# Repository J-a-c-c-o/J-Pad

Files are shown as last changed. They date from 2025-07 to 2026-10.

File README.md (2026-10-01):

# J-Pad

A custom 4x4 handwired macropad with rotary encoder, a configuration GUI and a
layout that survives a reboot.

<div style="display: flex; justify-content: center; gap: 20px;">
  Macropad Top View
  Macropad Side View
</div>

## Overview

This project is a handwired 4x4 macropad built around a Raspberry Pi Pico and QMK firmware. The firmware maps each physical key to a macro slot, and the host application in `host/` reads and writes those macros at runtime over raw HID.

The encoder has layer-aware behavior, and the firmware supports 16 logical layers with 16 macros per layer.

Layouts live in RAM while you edit them and are written to the flash of the Pico by an explicit save, so the board keeps its layout over a reboot. The host application talks to the board with a small request/response protocol over raw HID and ships a GUI that edits the layout the board is currently running.

## Requirements

### Hardware

- 1x Raspberry Pi Pico
- 16x Cherry MX compatible switches (or 15 switches plus encoder push if available)
- 1x Rotary encoder (EC11)
- 16x 1N4148 diodes
- 4x 3M 10mm DIN 965 screws (or similar)
- Hookup wire for handwiring
- Keycaps for 16 keys
- MX encoder adapter: [Thingiverse Thing:3770166](https://www.thingiverse.com/thing:3770166)

### Software

- [QMK Firmware](https://qmk.fm/) for firmware compilation/customization
- [Rust](https://www.rust-lang.org/tools/install) (stable) for the host application
- Computer with USB port

### Tools (for assembly)

- Soldering iron and solder
- Wire strippers
- 3D printer or printing service
- Basic hand tools

## Quick Start

### Flash Firmware

1. Hold the top-left key while plugging in USB.
2. Copy `jpad_4x4_macropad_default.uf2` to the `RPI-RP2` drive.
3. The board will reboot with the loaded firmware.

### Default Behavior

The firmware maps the 16 keys to macro indices `0..15` on every layer. The actual key behavior is defined by macros, so the board is configured from the host application in `host/`.

The first boot has no stored layout, so the firmware falls back to a built-in default layout: media keys, a mute key, function keys, a repeating left mouse button, and four keys that switch to the other layers. The encoder changes the volume on every layer, except for a few layers where it scrolls, zooms, scrolls again or skips tracks.

## Host Application

The host application is a single Rust binary called `jpad`, with a GUI for the
layout and a small CLI for scripting. It lives in `host/`.

```bash
cd host
cargo run --release
```

Press **Connect** and the layout the board is running appears in the pad. Click a
key to edit its steps, delay and auto repeat, click the knob in the top right
cell for the rotary encoder, and use the layer selector to switch layers. Keys you
changed get an outline, and the panel on the right shows the device, where its
layout came from and the keys it holds.

Switching layers keeps the key you are editing open, on the new layer.

The buttons along the bottom:

- **Read** re-reads the layout from the board, your edits are discarded after you confirm.
- **Write** sends your edited layout to the board, it is live right away but lost on a reboot.
- **Save** sends it and writes it into the flash of the Pico, this is what makes it survive a reboot.
- **Reset** puts the built-in defaults back into RAM, press **Save** to keep them.

While you have changes that are not on the board yet, the pad header says
`unsaved changes` and the bottom bar repeats it next to the buttons. The pill in
the title bar shows `saved` or `not saved`, which is the state of the board's own
flash.

### Command line

```bash
cargo run --release -- show    # print the layout the board is running
cargo run --release -- verify  # read, write back, read again and save to flash
cargo run --release -- demo    # send an example layout and save it
cargo run --release            # open the GUI, the default with no arguments
```

`show` and `demo` are meant as examples. `verify` leaves
the layout as it is and only proves that the whole path works, use it after
flashing new firmware.

### Recording keys

Instead of typing keycode names, arm **Record keys** in the key editor and just
press keys: every press becomes a step. Holding Ctrl, Shift or Alt while you
press a key records the combination, so Ctrl+C becomes `LCTL(KC_C)` and
Ctrl+Shift+C becomes `LCS(KC_C)`. Press Esc or the button again to stop.

The encoder editor has the same button. Click the direction you want to fill
first, then press keys.

Switching layers has its own shortcut: pick a number next to **Switch to layer**
and press **Add layer switch**, which appends `SWITCH_LAYER_0` to
`SWITCH_LAYER_15` as a step.

### Keycode reference

The **Keycodes** button in the title bar opens a searchable list of every keycode
the board understands, grouped by purpose, with the value each one has. Click an
entry to copy its name, then paste it into a step.

### Keycode expressions

Keycodes are written the way they are written in a keymap, and the host
converts them to raw QMK keycodes:

| Expression | Meaning |
| --- | --- |
| `KC_A`, `KC_F13`, `KC_KB_VOLUME_UP`, `MS_BTN1`  | plain keycodes |
| `LCTL(KC_C)`, `LSFT(KC_ENT)`, `RALT(KC_DELETE)` | one modifier, `C()`, `S()`, `A()` and `G()` are short hands for them |
| `LCSG(KC_TAB)`, `HYPR(KC_ENT)`, `MEH(KC_4)` | modifier combinations |
| `SWITCH_LAYER_0` .. `SWITCH_LAYER_15` | switch to that layer |
| `0x0104` | a raw keycode |

A step may hold up to 4 keycodes that are pressed together, and a macro may hold
up to 8 steps. Inside one step you can put both a layer switch and a key, for
example `SWITCH_LAYER_2, KC_TAB` goes to layer 2 and presses the tab key.

## How it works

### Talking to the board

The board exposes a raw HID interface (`FEED:0000`, usage page `FF60`, usage
`0061`). Every report is 32 bytes and carries one command, the device answers
request/response commands with a single report.

| Command | Value | Direction | Purpose |
| --- | ----- | --- | --- |
| `SET_ENCODER`  | 0 | host to device | counterclockwise and clockwise keycode of one layer |
| `SET_MACRO` | 1 | host to device | steps and delay of one macro slot, fragmented |
| `SET_REPEAT` | 2 | host to device | auto repeat interval of one macro slot |
| `GET_LAYOUT` | 3 | both | ask for one fragment of the whole layout |
| `SET_LAYOUT` | 4 | host to device | replace the whole layout, fragmented |
| `SAVE_LAYOUT`  | 5 | both | write the layout into flash, answered when the write finished |
| `RESET_LAYOUT` | 6 | both | load the built-in defaults into RAM |
| `PING` | 7 | both | device status, used to confirm a transfer finished |

Every value in a report is little endian.

Layouts are transferred as fragments. A request carries the total number of
fragments, the fragment index and up to 25 payload bytes, a response carries the
same for the layout the device serves. The host asks for one fragment at a time
and the device serializes the layout again for every request, so a lost fragment
is simply asked for again and neither side has to keep transfer state. A
fragmented write ends with a `PING` whose response proves the board consumed all
fragments, since raw HID reports are handled in order.

### The layout format

The layout is serialized to one little endian blob, the same format that is
stored in flash. It starts with a magic value, a version and its own length,
followed by the counts the layout was built with, then every macro slot of every
layer (step count, repeat interval, delay, and the steps with their keycodes) and
finally the encoder actions per layer. A blank layout is 1354 bytes, the largest layout
the limits allow is 19786 bytes.

The version in the header is checked on load, so a layout written by a future
firmware with a different format falls back to the defaults instead of being
applied as garbage.

### Storage

The layout is kept in the emulated EEPROM of the Pico, which is a wear leveled
region of 32 kB in the last 64 kB of the chip's flash. Only the bytes that
actually changed are written, and a save of an unchanged layout writes nothing.
The firmware uses about 104 kB of the 264 kB of RAM statically, the rest is left
for other things.

The layout is written only when the host sends `SAVE_LAYOUT`, never while you are
editing, so flash wear stays out of the way. The device answers the command after
the write finished, and the host retries if the answer is lost.

### Limits

- 16 layers, 16 macro slots per layer
- 8 steps per macro, 4 keycodes per step
- 5000 ms maximum delay and repeat interval, 0 turns auto repeat off

## Project Files

- `qmk-config/` - QMK keyboard definition and keymap sources
  - `qmk-config/jpad_4x4_macropad/keyboard.json` declares keyboard features
  - `qmk-config/jpad_4x4_macropad/keymaps/default/keymap.c` maps the keys to macro slots and runs the macros
  - `qmk-config/jpad_4x4_macropad/keymaps/default/jpad_config.c` holds the layout, serializes it and stores it in flash
  - `qmk-config/jpad_4x4_macropad/keymaps/default/jpad_protocol.c` implements the raw HID protocol
  - `qmk-config/jpad_4x4_macropad/keymaps/default/rules.mk` enables the wear leveled EEPROM
- `hardware/` - Handwiring guide, BOM, and assembly instructions
- `case/` - 3D printable case files
  - `case.3mf` - main case design
  - `case.f3d` - Fusion 360 design file
  - `stl/` - STL files for printing
- `images/` - Assembly and wiring reference photos
- `host/` - Rust host application, the `jpad` binary
  - `host/src/main.rs` - entry point and the `show`, `verify` and `demo` commands
  - `host/src/app.rs` - the GUI
  - `host/src/device.rs` - raw HID client
  - `host/src/layout.rs` - layout model and blob format
  - `host/src/keycode_converter.rs` - keycode expression parser and printer
  - `host/src/keycodes.rs` - mapping of pressed keys to keycodes, and the keycode reference

## Building Your Own

### 1. Print Required Parts

- Print `case.3mf`
- Print the MX encoder adapter from [Thingiverse Thing:3770166](https://www.thingiverse.com/thing:3770166)
- Recommended settings: 0.2mm layer height, 20% infill, PLA or PETG

### 2. Gather Components

See `hardware/README.md` for the full Bill of Materials.

### 3. Handwire Assembly

Follow `hardware/assembly.md` to:

- wire the switch matrix
- connect the Raspberry Pi Pico
- wire the encoder to GP26/GPIO28
- install the case and finish assembly

### 4. Flash Firmware

Use the Quick Start guide above or compile from QMK after copying the keyboard folder.

## Customizing

Copy `qmk-config/jpad_4x4_macropad/` into your local QMK firmware tree under `keyboards/`.

Example:

```bash
cp -r qmk-config/jpad_4x4_macropad ~/qmk_firmware/keyboards/
```

Then build and flash:

```bash
qmk compile -kb jpad_4x4_macropad -km default
qmk flash -kb jpad_4x4_macropad -km default
```

The size limits of the layout live in `jpad_config.h`. Raising them means raising
`WEAR_LEVELING_LOGICAL_SIZE` and `WEAR_LEVELING_BACKING_SIZE` in `rules.mk` as
well, and the blob has to stay smaller than the logical EEPROM size.

## Releases

`.github/workflows/release.yml` runs on every push to `main` and on every pull
request. It builds the QMK firmware and the `jpad` application for Linux, macOS
(Intel and Apple Silicon) and Windows, so a broken firmware or a broken build
shows up before you tag anything.

- `jpad_4x4_macropad_default.uf2`, the firmware to copy to the `RPI-RP2` drive
- `jpad-<target>`, the configuration application for your OS and architecture
  `

## Notes

- The stored layout lives in the flash of the Pico, so refashing the firmware with QMK keeps it, while the layout format version guards against incompatible changes.
- Layer switching is handled by macro keycodes such as `SWITCH_LAYER_0..SWITCH_LAYER_15`, they are plain keycodes starting at `QK_USER`, so keep the layer switch keycodes at the start of `SAFE_RANGE` in `jpad_config.h`.
- A macro runs its steps in order, the keycodes of a step are pressed and released together, and the delay of the macro is waited out after the last step. A step is over before the next one starts, so a held modifier has to be part of the same keycode, `LCTL(KC_C)` instead of `KC_LCTL` and `KC_C` in two steps.

## License

Open source hardware and software. See individual files for specific licenses.

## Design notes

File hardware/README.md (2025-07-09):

# Hardware - Handwired Build

## Overview

This is a handwired 4x4 macropad using a Raspberry Pi Pico microcontroller. No custom PCB required!

### Key Features
- Raspberry Pi Pico microcontroller
- 15x Cherry MX switches + 1x rotary encoder
- Handwired matrix (4x4 grid)
- USB-C connectivity via Pico
- 3D printed case

## Bill of Materials

| Component | Quantity | Description | Example Source |
|---|---|---|---|
| Raspberry Pi Pico | 1 | Microcontroller board | Any electronics supplier |
| Cherry MX switches | 15 | Mechanical switches | NovelKeys, Gateron, etc. |
| Rotary encoder | 1 | EC11 type recommended | Any electronics supplier |
| Diodes 1N4148 | 16 | Through-hole diodes | Any electronics supplier |
| Wire | ~2m | 30AWG wire wrap wire | Amazon, electronics stores |
| Screws | 4 | 3M 10mm DIN 965 screws (or similar) | Amazon, hardware stores |
| Keycaps | 15 | Any MX compatible | Amazon, mechanical keyboard stores |

**Special Part**: MX Switch Adapter for Encoder
- Download from [Thingiverse Thing:3770166](https://www.thingiverse.com/thing:3770166)
- 3D print this adapter to mount the encoder in an MX switch position
- Allows encoder to fit in the standard switch grid

## Wiring Diagram

### Matrix Layout
```
     Col0  Col1  Col2  Col3
     GP9   GP11  GP13  GP15
Row0 SW1   SW2   SW3   ENC   GP18
Row1 SW4   SW5   SW6   SW7   GP22
Row2 SW8   SW9   SW10  SW11  GP20
Row3 SW12  SW13  SW14  SW15  GP16
```

### Pin Assignments
```
Matrix pins:
- Rows: GP18, GP22, GP20, GP16
- Cols: GP9, GP11, GP13, GP15

Encoder pins:
- Pin A: GP26
- Pin B: GP28
```

### Diode Placement
- One 1N4148 diode per switch (including encoder position)
- Cathode (striped end) connects to column wire
- Anode connects to switch pin
- Prevents key ghosting in matrix

## Assembly Guide

See `assembly.md` for complete step-by-step handwiring instructions including:
- Matrix wiring techniques
- Pico connection details
- Testing procedures
- Troubleshooting tips

## Alternative Builds

### Without Encoder Switch
- Wire only encoder A/B pins (rotation)
- Leave switch pin unconnected
- Use regular switch in position [0,3] or leave empty

### Different Switch Count
- Can reduce to 3x4 (12 switches) if desired
- Update QMK configuration accordingly
- Adjust case design as needed

## Advantages of Handwiring
- **No PCB required** - cheaper and more accessible
- **Easy to modify** - change layout anytime
- **Learning experience** - understand how keyboards work
- **Repairable** - easy to fix broken connections

## Tools Required
- Soldering iron and solder
- Wire strippers
- Flush cutters
- Multimeter (for testing)
- 3D printer (for case and encoder adapter)

## Cost Estimate
- Raspberry Pi Pico: $4
- Switches: $15-30 (depending on type)
- Encoder: $2
- Diodes and wire: $5
- Keycaps + case: free (if printed)
- Screws: $2
- **Total: ~$20-40** (much cheaper than custom PCB)

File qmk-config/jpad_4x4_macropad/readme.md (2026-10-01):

# J-Pad 4x4

J-Pad 4x4

A 4x4 grid of rotary encoders with a push switch in each one, on a Raspberry Pi
Pico. Every key and every encoder can be mapped separately, and the encoder
pushes can each have their own tap, hold and double tap actions.

The layout lives in the flash of the Pico, so it survives a reboot and a
reflash of the firmware.

For wiring, the guide for building it and the host application that edits the
layout, see the [project readme](../../README.md).

## Flashing

Hold the top left encoder while plugging the board in, a `RPI-RP2` drive
appears, and `jpad_4x4_macropad_default.uf2` from the releases page is copied to
it.

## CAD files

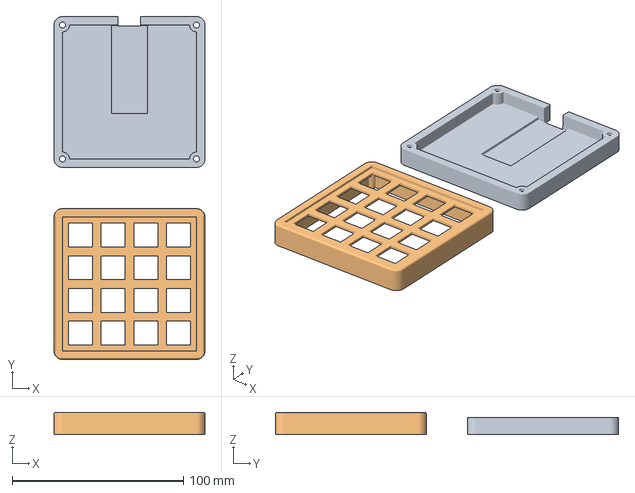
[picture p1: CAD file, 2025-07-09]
case/case.3mf
88.2 x 200.4 x 13.0 mm
Bottom
Top

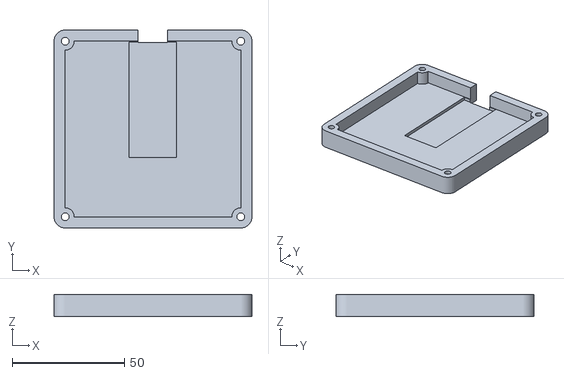
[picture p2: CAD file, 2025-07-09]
case/stl/Bottom.stl
88.2 x 88.2 x 10.0

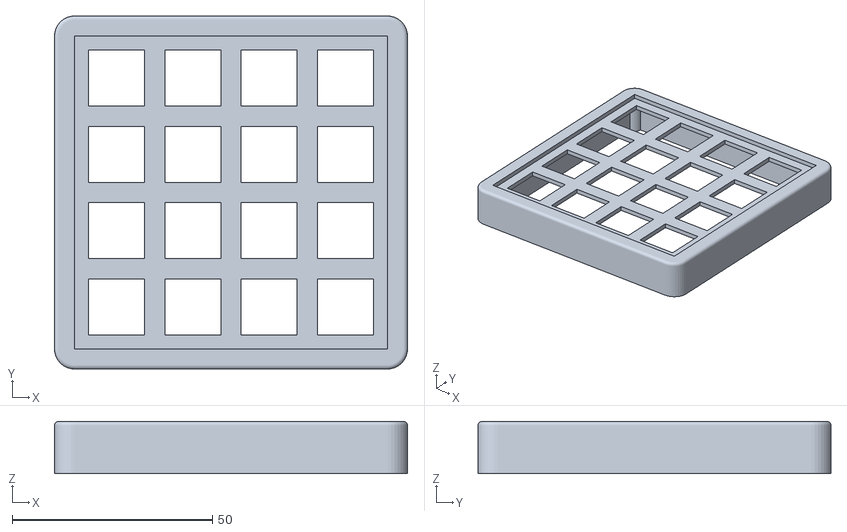
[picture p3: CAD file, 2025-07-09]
case/stl/Top.stl
88.2 x 88.2 x 13.0

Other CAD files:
case/case.f3d

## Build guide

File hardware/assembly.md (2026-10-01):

# Handwired Assembly Instructions

## Required Components
- 1x Raspberry Pi Pico
- 15x Cherry MX compatible switches
- 1x Rotary encoder (EC11)
- 16x 1N4148 diodes (through-hole)
- 30AWG wire wrap wire or similar
- 4x 3M 10mm DIN 965 screws (or similar)
- MX switch adapter for encoder: [Thingiverse Thing:3770166](https://www.thingiverse.com/thing:3770166)

## Required Tools
- Soldering iron (temperature controlled, 300-350°C)
- Solder (0.6-0.8mm, lead-free)
- Wire strippers
- Flush cutters
- Multimeter
- Hot glue gun (optional, for strain relief)

## Wiring Plan

### Matrix Layout (4x4 grid, position [0,3] is encoder)
```
     Col0  Col1  Col2  Col3
Row0  SW1   SW2   SW3   ENC
Row1  SW4   SW5   SW6   SW7  
Row2  SW8   SW9   SW10  SW11
Row3  SW12  SW13  SW14  SW15
```

### Pin Assignments (Raspberry Pi Pico)
```
Matrix:
- Rows: GP18, GP22, GP20, GP16
- Cols: GP9, GP11, GP13, GP15

Encoder:
- Pin A: GP26  
- Pin B: GP28
```

## Assembly Steps

### Wiring Progress Photos

The following photos show the progression of wiring the macropad:

**Step 1: Row Wiring**
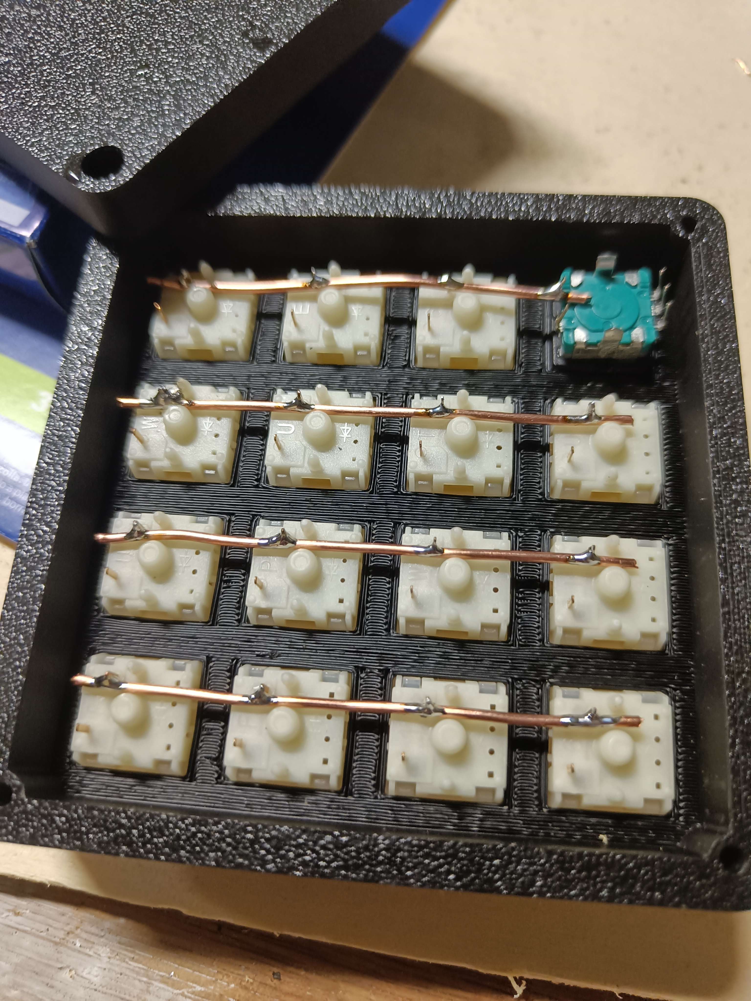
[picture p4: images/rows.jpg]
Row Wiring


**Step 2: Adding Diodes**
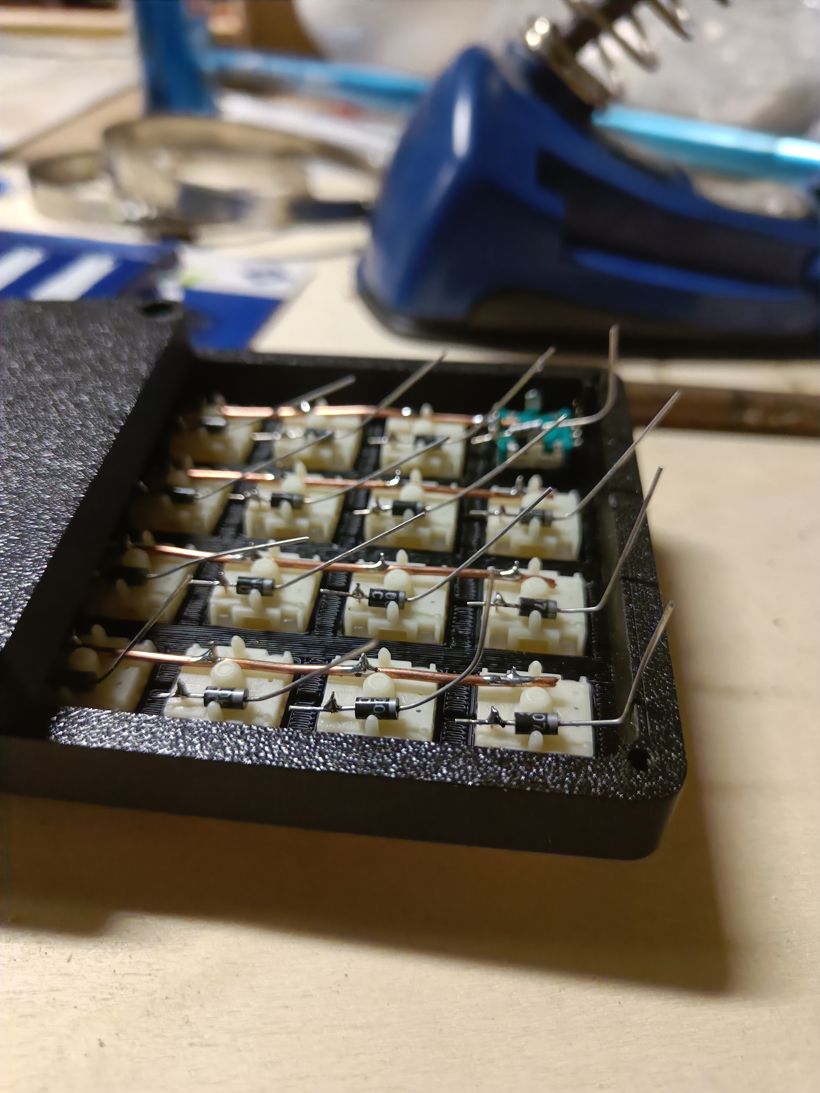
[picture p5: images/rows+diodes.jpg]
Rows with Diodes


**Step 3: Column Wiring**
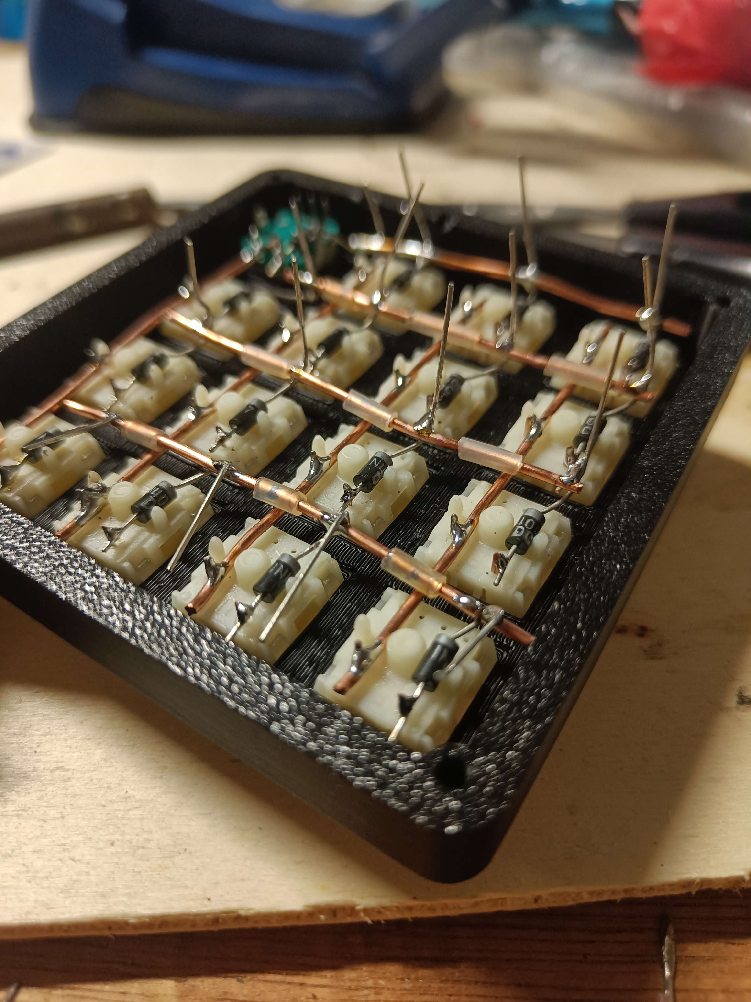
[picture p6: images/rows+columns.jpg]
Complete Matrix


**Step 4: Final Assembly with Pi Pico**
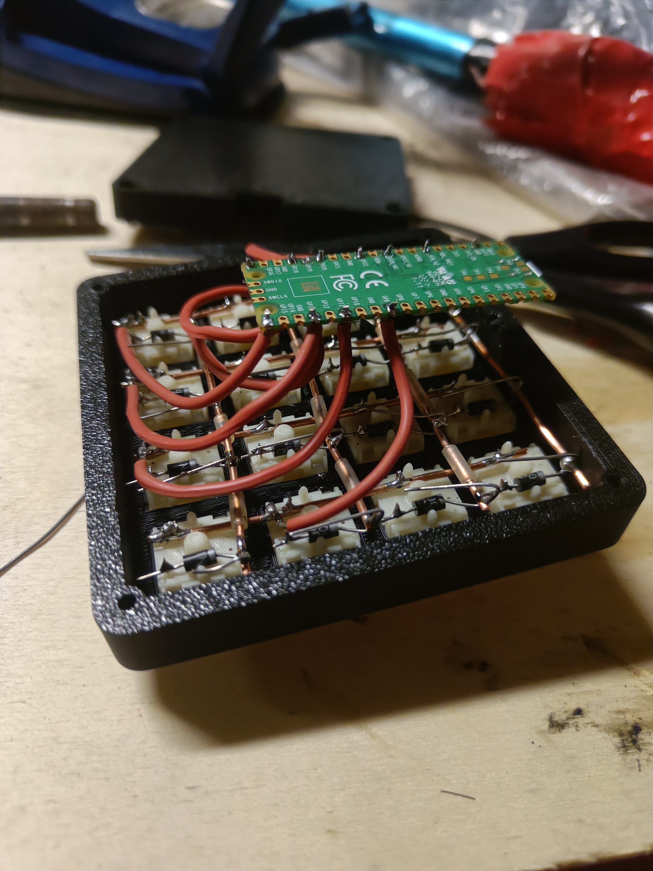
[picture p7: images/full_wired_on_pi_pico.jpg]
Fully Wired Macropad


### 1. Prepare the Case and Switches

1. **Print the MX adapter**
   - Download from [Thingiverse Thing:3770166](https://www.thingiverse.com/thing:3770166)
   - Print with 0.2mm layer height, 20% infill
   - Install encoder in adapter, then adapter in switch plate

2. **Install switches**
   - Place 15 switches in positions [0,0], [0,1], [0,2], [1,0] through [3,2] 
   - Position [0,3] has the encoder with MX adapter
   - Ensure all switches click properly

### 2. Install Diodes

1. **Diode placement**
   - Install one 1N4148 diode per switch (16 total, including encoder position)
   - Cathode (stripe) connects to the column wire
   - Anode connects to switch pin

2. **Solder diodes**
   - Bend diode legs to fit between switch pins
   - Solder cathode to one switch pin
   - Leave anode leg long for column wiring

### 3. Wire the Matrix

**Start with rows (easier to trace):**

1. **Row wires**
   - Strip and tin wire ends
   - Connect all switches in each row with single wire
   - Row 0: Connect SW1, SW2, SW3, and ENC
   - Row 1: Connect SW4, SW5, SW6, SW7
   - Row 2: Connect SW8, SW9, SW10, SW11  
   - Row 3: Connect SW12, SW13, SW14, SW15

2. **Column wires**
   - Connect diode cathodes in each column
   - Col 0: SW1, SW4, SW8, SW12 diodes
   - Col 1: SW2, SW5, SW9, SW13 diodes
   - Col 2: SW3, SW6, SW10, SW14 diodes
   - Col 3: ENC, SW7, SW11, SW15 diodes

### 4. Connect to Raspberry Pi Pico

1. **Row connections**
   - Row 0 → GP18
   - Row 1 → GP22  
   - Row 2 → GP20
   - Row 3 → GP16

2. **Column connections**
   - Col 0 → GP9
   - Col 1 → GP11
   - Col 2 → GP13
   - Col 3 → GP15

3. **Encoder connections**
   - Encoder Pin A → GP26
   - Encoder Pin B → GP28

## Testing

### Continuity Check
1. **Matrix test**: Use multimeter in continuity mode
   - Press switch, should show continuity between row and column
   - No continuity when switch not pressed
2. **Encoder test**: Turn encoder, should see changing resistance between A/B pins

### Programming Test
1. **Enter bootloader**
   - Hold BOOTSEL button on Pico while connecting USB
   - Pico should appear as mass storage device (RPI-RP2)

2. **Flash firmware**
   - Copy `firmware/jpad_4x4_macropad_default.uf2` to RPI-RP2 drive
   - Device will reboot automatically

3. **Function test**
   - Test each switch position
   - Test encoder rotation
   - Use online keyboard tester if needed

## Troubleshooting

**Common Issues:**
- **Switch not working**: Check diode polarity and solder joints
- **Multiple keys triggered**: Check for shorts between rows/columns
- **Encoder not working**: Verify A/B pin connections and wiring
- **No USB detection**: Check Pico solder joints and USB cable

**Wiring Tips:**
- Use different colored wires for rows vs columns
- Keep wires flat against PCB to fit in case
- Add strain relief with hot glue at connection points
- Test each connection before final assembly

## Alternative: No Encoder Switch

If you prefer not to wire the encoder switch:
1. Wire encoder A/B pins only (GP26, GP28)
2. Leave encoder switch pin unconnected
3. Use a different switch in position [0,3] or leave empty
4. Encoder rotation will still work for volume control

## Final Assembly
1. **Clean up wiring** with zip ties or tape
2. **Test fit in case** before final assembly  
3. **Install Pico** with hot glue or double-sided tape
4. **Close case** and screw together with 4x 3M 10mm screws
5. **Final function test** of all keys and encoder

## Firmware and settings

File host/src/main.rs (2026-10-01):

mod app;
mod device;
mod keycode_converter;
mod keycodes;
mod layout;

use std::error::Error;

use eframe::egui;

use keycode_converter::{Key, KeyExprBuilder as Expr, Modifier, step_expr};
use layout::Layout;

fn usage() {
    eprintln!("usage: jpad [gui|show|verify|demo]");
    eprintln!("  gui   open the layout editor (default)");
    eprintln!("  show  print the layout the device currently has in RAM");
    eprintln!("  verify  read, write back, read again and save to flash");
    eprintln!("  demo  send an example layout with the granular commands");
}

fn main() {
    if let Err(error) = run() {
        eprintln!("error: {error}");
        std::process::exit(1);
    }
}

fn run() -> Result<(), Box<dyn Error>> {
    match std::env::args().nth(1).as_deref() {
        None | Some("gui") => run_gui(),
        Some("show") => show(),
        Some("verify") => verify(),
        Some("demo") => demo(),
        Some(other) => {
            usage();
            eprintln!("unknown command: {other}");
            std::process::exit(2);
        }
    }
}

fn run_gui() -> Result<(), Box<dyn Error>> {
    let options = eframe::NativeOptions {
        viewport: egui::ViewportBuilder::default()
            .with_inner_size([1040.0, 720.0])
            .with_min_inner_size([860.0, 600.0]),
        ..Default::default()
    };

    eframe::run_native(
        "J-Pad Keyboard Configuration",
        options,
        Box::new(|_cc| Ok(Box::new(app::JPadApp::default()))),
    )
    .map_err(|error| -> Box<dyn Error> { Box::new(std::io::Error::other(error.to_string())) })
}

fn demo() -> Result<(), Box<dyn Error>> {
    let mut device = device::Device::open()?;
    println!("connected to {}", device.description());

    let status = device.ping()?;
    println!("device reports {}", status.summary());

    device.set_macro(0, 4, &[step_expr(&[Expr::switch_layer(5)])?], 0)?;

    device.set_macro(
        5,
        5,
        &[
            step_expr(&[Expr::with_mod(Modifier::Lctl, Expr::key(Key::C))])?,
            step_expr(&[Expr::key(Key::Delete)])?,
        ],
        50,
    )?;

    device.set_macro(5, 6, &[step_expr(&[Expr::key(Key::Num7)])?], 0)?;
    device.set_repeat(5, 6, 100)?;

    device.set_encoder(
        5,
        step_expr(&[Expr::key(Key::B)])?[0],
        step_expr(&[Expr::key(Key::A)])?[0],
    )?;

    device.set_macro(5, 4, &[step_expr(&[Expr::switch_layer(0)])?], 0)?;

    device.save_layout()?;
    println!("layout saved in flash");

    let layout = device.read_layout()?;
    print_layer(&layout, 0);
    print_layer(&layout, 5);

    Ok(())
}

fn verify() -> Result<(), Box<dyn Error>> {
    let mut device = device::Device::open()?;
    let status = device.ping()?;
    println!("connected to {}", device.description());
    println!("device reports {}", status.summary());

    let before = device.read_layout()?;
    println!("read {} bytes", before.to_bytes().len());

    device.write_layout(&before)?;
    let after = device.read_layout()?;
    if before == after {
        println!("write and read back match");
    } else {
        println!("write and read back differ, the device changed the layout");
    }

    device.save_layout()?;
    let status = device.ping()?;
    println!("saved {} bytes to flash", status.stored_bytes);

    println!("unplug and replug the board, then run this again to see if it survived");
    Ok(())
}

fn show() -> Result<(), Box<dyn Error>> {
    let mut device = device::Device::open()?;
    let status = device.ping()?;
    println!("connected to {}", device.description());
    println!("device reports {}", status.summary());
    if status.unsaved_changes {
        println!("the device has layout changes that are not in flash");
    }

    let layout = device.read_layout()?;
    for layer in 0..layout.layers.len() {
        print_layer(&layout, layer);
    }

    Ok(())
}

fn print_layer(layout: &Layout, index: usize) {
    let Some(layer) = layout.layers.get(index) else {
        return;
    };

    println!("layer {index}");
    for (index, slot) in layer.macros.iter().enumerate() {
        let steps: Vec<String> = (0..slot.steps.len())
            .map(|step| slot.step_text(step))
            .filter(|text| !text.is_empty())
            .collect();

        if steps.is_empty() && slot.repeat_ms == 0 {
            continue;
        }

        let repeat = if slot.repeat_ms == 0 {
            "off".to_string()
        } else {
            format!("{}ms", slot.repeat_ms)
        };
        println!(
            "  K{:<2} {:<28} delay {:>4}ms repeat {repeat}",
            index + 1,
            steps.join(" then "),
            slot.delay_ms,
        );
    }

    println!(
        "  encoder ccw {} cw {}",
        keycode_converter::keycode_to_expr(layer.counterclockwise),
        keycode_converter::keycode_to_expr(layer.clockwise)
    );
}

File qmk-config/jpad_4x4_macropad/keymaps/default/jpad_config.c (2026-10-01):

// SPDX-License-Identifier: GPL-2.0-or-later
#include "jpad_config.h"

#include <string.h>

#include "debug.h"
#include "util.h"
#include "wear_leveling.h"

static jpad_macro_t macros[JPAD_NUM_LAYERS][JPAD_NUM_MACROS];
static jpad_encoder_t encoders[JPAD_NUM_LAYERS];
static bool layout_dirty = false;
static jpad_layout_source_t layout_source = JPAD_LAYOUT_SOURCE_DEFAULTS;
static uint16_t stored_length = 0;

static uint8_t persist_buffer[JPAD_BLOB_MAX];

static bool is_layer_keycode(uint16_t keycode) {
  return keycode >= SWITCH_LAYER_0 && keycode <= SWITCH_LAYER_15;
}

typedef struct {
  uint8_t *buffer;
  uint16_t length;
  uint16_t capacity;
  bool ok;
} blob_writer_t;

typedef struct {
  const uint8_t *buffer;
  uint16_t length;
  uint16_t offset;
  bool ok;
} blob_reader_t;

static void writer_put_u8(blob_writer_t *writer, uint8_t value) {
  if (!writer->ok || writer->length + 1 > writer->capacity) {
    writer->ok = false;
    return;
  }
  writer->buffer[writer->length++] = value;
}

static void writer_put_u16(blob_writer_t *writer, uint16_t value) {
  writer_put_u8(writer, (uint8_t)(value & 0xFF));
  writer_put_u8(writer, (uint8_t)(value >> 8));
}

static bool reader_take_u8(blob_reader_t *reader, uint8_t *out) {
  if (!reader->ok || reader->offset + 1 > reader->length) {
    reader->ok = false;
    return false;
  }
  *out = reader->buffer[reader->offset++];
  return true;
}

static bool reader_take_u16(blob_reader_t *reader, uint16_t *out) {
  uint8_t low, high;
  if (!reader_take_u8(reader, &low) || !reader_take_u8(reader, &high)) {
    return false;
  }
  *out = (uint16_t)((uint16_t)high << 8 | low);
  return true;
}

static void set_default_macro(jpad_macro_t *macro, uint16_t keycode,
                              uint16_t repeat_interval) {
  memset(macro, 0, sizeof(*macro));
  macro->repeat_interval = repeat_interval;
  if (keycode != KC_NO) {
    macro->steps[0].key_count = 1;
    macro->steps[0].keys[0] = keycode;
    macro->step_count = 1;
  }
}

void jpad_config_load_defaults(void) {
  memset(macros, 0, sizeof(macros));

  for (uint8_t layer = 0; layer < JPAD_NUM_LAYERS; layer++) {
    set_default_macro(&macros[layer][0], KC_MPRV, 0);
    set_default_macro(&macros[layer][1], KC_MPLY, 0);
    set_default_macro(&macros[layer][2], KC_MNXT, 0);
    set_default_macro(&macros[layer][3], SWITCH_LAYER_0, 0);
    set_default_macro(&macros[layer][4], KC_F13, 0);
    set_default_macro(&macros[layer][5], KC_F14, 0);
    set_default_macro(&macros[layer][6], KC_F15, 0);
    set_default_macro(&macros[layer][7], KC_MUTE, 0);
    set_default_macro(&macros[layer][8], KC_F16, 0);
    set_default_macro(&macros[layer][9], KC_F17, 0);
    set_default_macro(&macros[layer][10], KC_F18, 0);
    set_default_macro(&macros[layer][11], MS_BTN1, 100);
    set_default_macro(&macros[layer][12], SWITCH_LAYER_1, 0);
    set_default_macro(&macros[layer][13], SWITCH_LAYER_2, 0);
    set_default_macro(&macros[layer][14], SWITCH_LAYER_3, 0);
    set_default_macro(&macros[layer][15], SWITCH_LAYER_4, 0);

    encoders[layer].counterclockwise = KC_VOLD;
    encoders[layer].clockwise = KC_VOLU;
  }

  encoders[1].counterclockwise = KC_LEFT;
  encoders[1].clockwise = KC_RIGHT;
  encoders[2].counterclockwise = C(KC_MINS);
  encoders[2].clockwise = C(KC_EQL);
  encoders[3].counterclockwise = MS_WHLD;
  encoders[3].clockwise = MS_WHLU;
  encoders[4].counterclockwise = KC_MPRV;
  encoders[4].clockwise = KC_MNXT;
}
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
